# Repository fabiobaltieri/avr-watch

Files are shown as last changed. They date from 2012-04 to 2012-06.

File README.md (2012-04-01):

AVR Watch
=========

This project is small wrist watch using an AVR microcontroller, a 7-segment
display and the V-USB soft-usb stack.

License
-------

This program is free software: you can redistribute it and/or modify
it under the terms of the GNU General Public License as published by
the Free Software Foundation, either version 2 of the License, or
(at your option) any later version.

Contents
--------

    COPYING     text version of the GPL
    README      this file
    bootloader/ source directory for bootloader
    firmware/   source directory for firmware
    hardware/   source directory for the hardware design
    scripts/    support scripts

Bootloader
----------

Building the bootloader requires an avr-gcc toolchain, in the bootloader/
directory, to build run:

    make

Flashing the firmware on the device requires avrdude and a compatible hardware
programmer. Default configuration is stored at the beginning of the Makefile.
To program with the default configuration, run:

    make load

Fuses can be programmed running:

    make fuse

Firmware
--------

Building the firmwware requires an avr-gcc toolchain, in the firmware/
directory, to build run:

    make

Flashing the firmware on the device requires avrdude and a compatible hardware
programmer. Default configuration is stored at the beginning of the Makefile.
To program with the default configuration, run:

    make load

or using the bootloader (this will reset the device if possible):

    make boot

Hardware
--------

All hardware files (schematic, layout and libraries) are in CadSoft Eagle
format.

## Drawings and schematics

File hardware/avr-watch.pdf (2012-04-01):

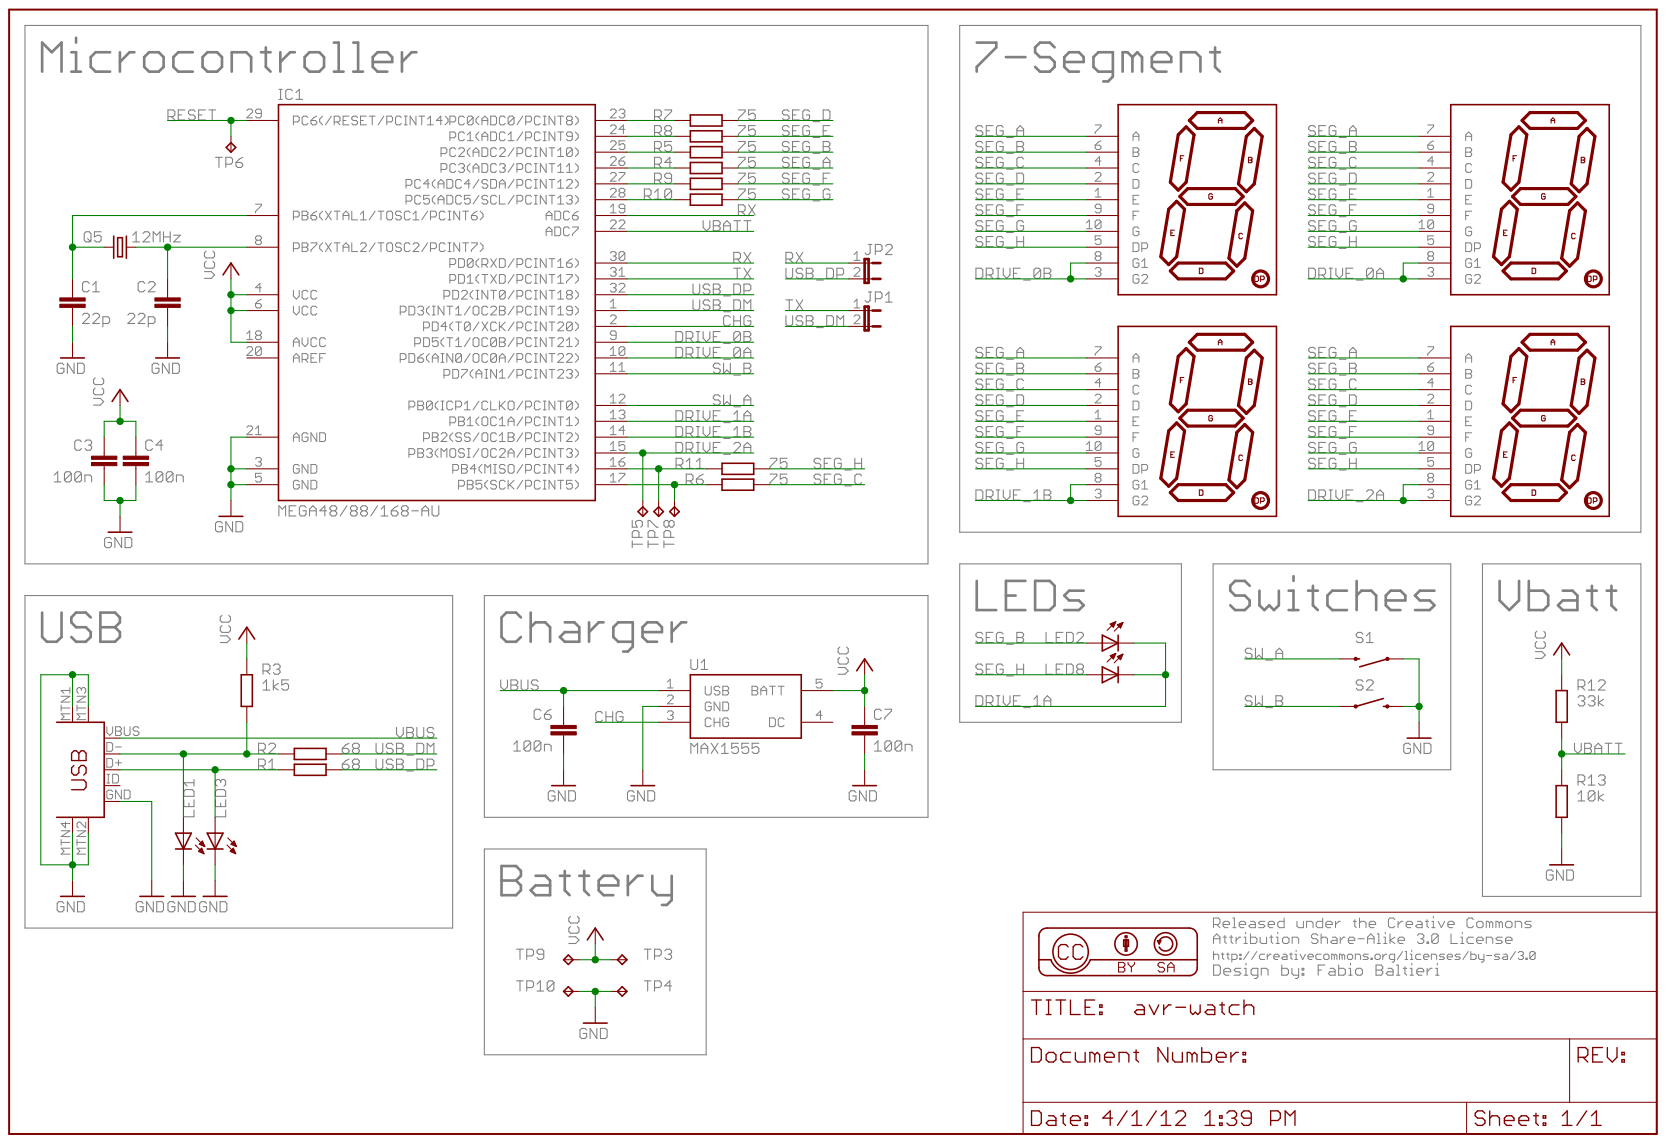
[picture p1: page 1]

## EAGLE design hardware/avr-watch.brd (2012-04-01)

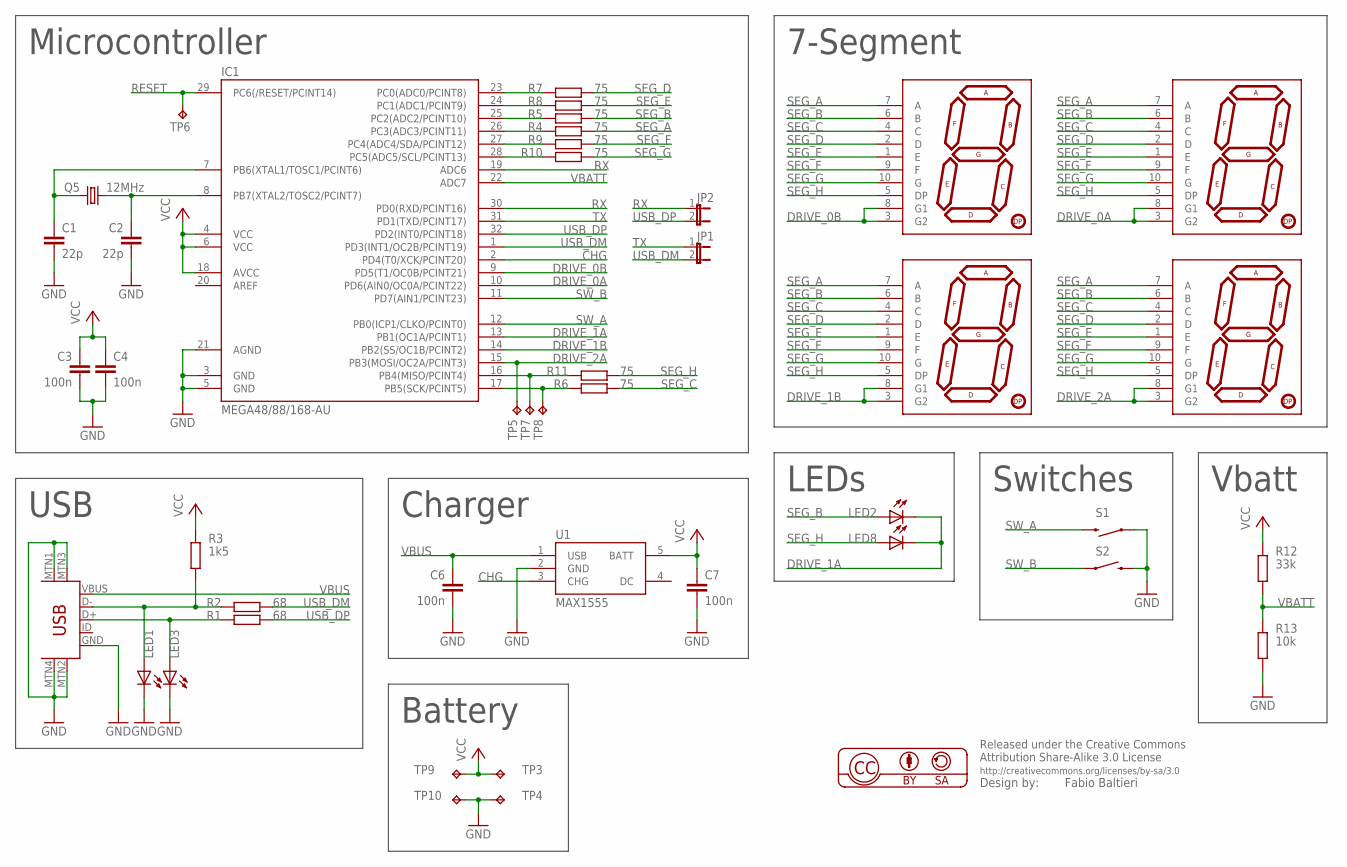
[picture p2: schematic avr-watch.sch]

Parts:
C1, C2: 22p; C0805
C3, C4, C6, C7: 100n; C0805
IC1: MEGA48/88/168-AU; TQFP32-08
JP1, JP2: JUMPER-2SMD-NC; SJ_2S
LED1, LED2, LED3, LED8: LEDCHIPLED_1206; CHIPLED_1206
Q5: 12MHz; CTS406
R1, R2: 68; R0603
R3: 1k5; R0603
R4, R5, R6, R7, R8, R9, R10, R11: 75; R0603
R12: 33k; R0603
R13: 10k; R0603
S1, S2: SWITCH-MOMENTARY-2SMD; TACTILE_SWITCH_SMD
TP3, TP4: TPB1,27; B1,27
TP5, TP6, TP7, TP8, TP9, TP10: TPTP08R; TP08R
U1: MAX1555; SOT23-5
U$1, U$3, U$4, U$5: 7-SEGMENT-DISPLAY-1"-RED; 7-SEGMENT-SMD
U$2: USB-MINIB-5PIN; USB-MINIB

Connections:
CHG: IC1.2 (PD4(T0/XCK/PCINT20)), U1.3 (CHG)
DRIVE_0A: IC1.10 (PD6(AIN0/OC0A/PCINT22)), U$3.3 (G2), U$3.8 (G1)
DRIVE_0B: IC1.9 (PD5(T1/OC0B/PCINT21)), U$1.3 (G2), U$1.8 (G1)
DRIVE_1A: IC1.13 (PB1(OC1A/PCINT1)), LED2.C, LED8.C
DRIVE_1B: IC1.14 (PB2(SS/OC1B/PCINT2)), U$4.3 (G2), U$4.8 (G1)
DRIVE_2A: IC1.15 (PB3(MOSI/OC2A/PCINT3)), TP5.TP, U$5.3 (G2), U$5.8 (G1)
GND: C1.2, C2.2, C3.2, C4.2, C6.2, C7.2, IC1.3 (GND), IC1.5 (GND), IC1.21 (AGND), LED1.C, LED3.C, R13.1, S1.1, S2.3 (2), TP4.TP, TP10.TP, U1.2 (GND), U$2.GND, U$2.MTN1 (MTN2), U$2.MTN2 (MTN3), U$2.MTN3 (MTN1), U$2.MTN4
unnamed: C2.1, IC1.8 (PB7(XTAL2/TOSC2/PCINT7)), Q5.3 (2)
unnamed: C1.1, IC1.7 (PB6(XTAL1/TOSC1/PCINT6)), Q5.1
unnamed: IC1.16 (PB4(MISO/PCINT4)), R11.1, TP7.TP
unnamed: IC1.17 (PB5(SCK/PCINT5)), R6.1, TP8.TP
unnamed: IC1.24 (PC1(ADC1/PCINT9)), R8.1
unnamed: IC1.25 (PC2(ADC2/PCINT10)), R5.1
unnamed: IC1.26 (PC3(ADC3/PCINT11)), R4.1
unnamed: IC1.27 (PC4(ADC4/SDA/PCINT12)), R9.1
unnamed: IC1.23 (PC0(ADC0/PCINT8)), R7.1
unnamed: IC1.28 (PC5(ADC5/SCL/PCINT13)), R10.1
unnamed: LED1.A, R2.1, R3.1, U$2.D-
unnamed: LED3.A, R1.1, U$2.D+
RESET: IC1.29 (PC6(/RESET/PCINT14)), TP6.TP
RX: IC1.19 (ADC6), IC1.30 (PD0(RXD/PCINT16)), JP2.1
SEG_A: R4.2, U$1.7 (A), U$3.7 (A), U$4.7 (A), U$5.7 (A)
SEG_B: LED2.A, R5.2, U$1.6 (B), U$3.6 (B), U$4.6 (B), U$5.6 (B)
SEG_C: R6.2, U$1.4 (C), U$3.4 (C), U$4.4 (C), U$5.4 (C)
SEG_D: R7.2, U$1.2 (D), U$3.2 (D), U$4.2 (D), U$5.2 (D)
SEG_E: R8.2, U$1.1 (E), U$3.1 (E), U$4.1 (E), U$5.1 (E)
SEG_F: R9.2, U$1.9 (F), U$3.9 (F), U$4.9 (F), U$5.9 (F)
SEG_G: R10.2, U$1.10 (G), U$3.10 (G), U$4.10 (G), U$5.10 (G)
SEG_H: LED8.A, R11.2, U$1.5 (DP), U$3.5 (DP), U$4.5 (DP), U$5.5 (DP)
SW_A: IC1.12 (PB0(ICP1/CLKO/PCINT0)), S1.3 (2)
SW_B: IC1.11 (PD7(AIN1/PCINT23)), S2.1
TX: IC1.31 (PD1(TXD/PCINT17)), JP1.1
USB_DM: IC1.1 (PD3(INT1/OC2B/PCINT19)), JP1.2, R2.2
USB_DP: IC1.32 (PD2(INT0/PCINT18)), JP2.2, R1.2
VBATT: IC1.22 (ADC7), R12.1, R13.2
VBUS: C6.1, U1.1 (USB), U$2.VBUS
VCC: C3.1, C4.1, C7.1, IC1.4 (VCC), IC1.6 (VCC), IC1.18 (AVCC), R3.2, R12.2, TP3.TP, TP9.TP, U1.5 (BATT)

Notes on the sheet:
USB
Microcontroller
7-Segment
LEDs
Charger
Switches
Vbatt
Battery

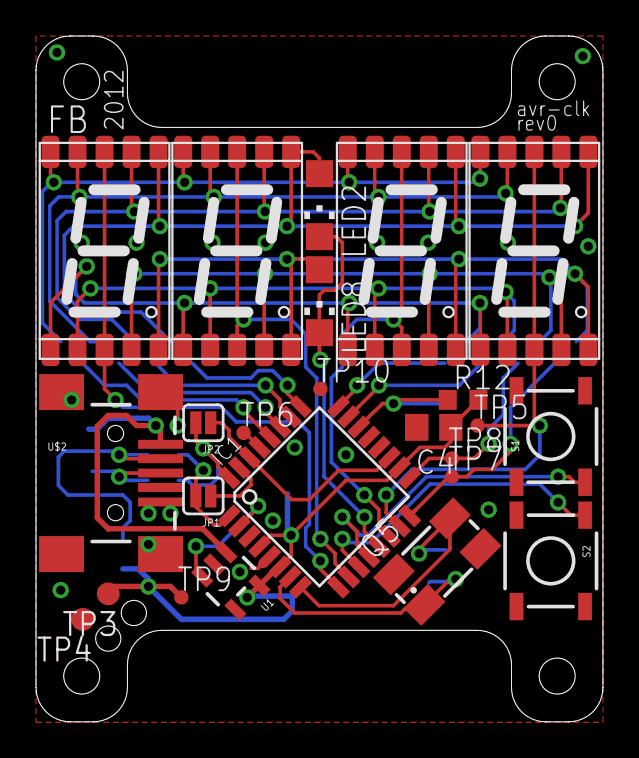
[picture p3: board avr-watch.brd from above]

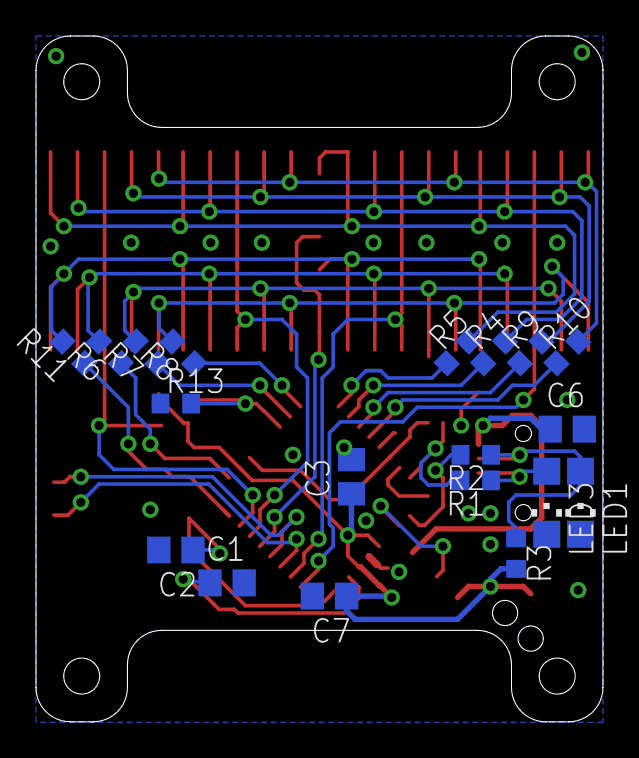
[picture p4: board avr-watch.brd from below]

Board: 2 copper layers, 31.5 x 38.1 mm, 43 parts (19 on the bottom side), 37 nets.

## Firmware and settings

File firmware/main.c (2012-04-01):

/*
 * Copyright 2012 Fabio Baltieri (fabio.baltieri@gmail.com)
 *
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
 */

#include "board.h"

#include <avr/io.h>
#include <avr/wdt.h>
#include <avr/interrupt.h>
#include <avr/sleep.h>
#include <util/delay.h>

#include "usbdrv.h"
#include "requests.h"

#include "clock.h"

/*
 * USB
 */

static void reset_cpu(void)
{
	wdt_disable();

	wdt_enable(WDTO_15MS);

	for (;;);
}

usbMsgLen_t usbFunctionSetup(uint8_t data[8])
{
	struct usbRequest *rq = (void *)data;
	static union {
		uint32_t l;
		uint8_t  b[4];
	} temp;

	switch (rq->bRequest) {
	case CUSTOM_RQ_GET_TIME:
		temp.l = time;
		usbMsgPtr = (uint8_t *)&temp;
		return sizeof(temp);
	case CUSTOM_RQ_SET_TIME:
		temp.b[0] = rq->wValue.bytes[0];
		temp.b[1] = rq->wValue.bytes[1];
		temp.b[2] = rq->wIndex.bytes[0];
		temp.b[3] = rq->wIndex.bytes[1];
		time = temp.l;
		return 0;
	case CUSTOM_RQ_RESET:
		reset_cpu();
		break;
	}

	return 0;
}

/*
 * Main & Friends
 */

static void hello(void)
{
	uint8_t i;
	drive_0(1);
	for (i = 0; i < 8; i++) {
		led_set(0xff);
		_delay_ms(33);
		led_set(0x00);
		_delay_ms(33);
	}
	drive_0(0);
}

int __attribute__((noreturn)) main(void)
{
	uint8_t i;

	/* disable watchdog */
	i = MCUSR;
	MCUSR = 0;
	wdt_disable();

	/* power down unused peripherals */
	PRR = ( (1 << PRTWI) |    /* TWI */
		(0 << PRTIM0) |   /* Timer 0 */
		(0 << PRTIM1) |   /* Timer 1 */
		(1 << PRTIM2) |   /* Timer 2 */
		(1 << PRSPI) |    /* SPI */
		(1 << PRUSART0) | /* USART0 */
		(0 << PRADC) );   /* ADC */

	/* clock */
	led_init();
	clock_init();
	hello();

	/* USB */
	usbInit();
	usbDeviceDisconnect();

	i = 0;
	while (--i) {
		_delay_ms(1);
	}

	usbDeviceConnect();

	sei();
	for (;;) {
		usbPoll();

		clock_poll();

		set_sleep_mode(SLEEP_MODE_IDLE);
		sleep_mode();
	}
}

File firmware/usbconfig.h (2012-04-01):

/*
 * Author: Fabio Baltieri
 * Original Author: Christian Starkjohann
 * Copyright: (c) 2005 by OBJECTIVE DEVELOPMENT Software GmbH
 * License: GNU GPL v2 (see License.txt)
 *
 */

#ifndef __usbconfig_h_included__
#define __usbconfig_h_included__

/*
General Description:
This file is an example configuration (with inline documentation) for the USB
driver. It configures V-USB for USB D+ connected to Port D bit 2 (which is
also hardware interrupt 0 on many devices) and USB D- to Port D bit 4. You may
wire the lines to any other port, as long as D+ is also wired to INT0 (or any
other hardware interrupt, as long as it is the highest level interrupt, see
section at the end of this file).
+ To create your own usbconfig.h file, copy this file to your project's
+ firmware source directory) and rename it to "usbconfig.h".
+ Then edit it accordingly.
*/

/* ---------------------------- Hardware Config ---------------------------- */

#define USB_CFG_IOPORTNAME      D
/* This is the port where the USB bus is connected. When you configure it to
 * "B", the registers PORTB, PINB and DDRB will be used.
 */
#define USB_CFG_DMINUS_BIT      3
/* This is the bit number in USB_CFG_IOPORT where the USB D- line is connected.
 * This may be any bit in the port.
 */
#define USB_CFG_DPLUS_BIT       2
/* This is the bit number in USB_CFG_IOPORT where the USB D+ line is connected.
 * This may be any bit in the port. Please note that D+ must also be connected
 * to interrupt pin INT0! [You can also use other interrupts, see section
 * "Optional MCU Description" below, or you can connect D- to the interrupt, as
 * it is required if you use the USB_COUNT_SOF feature. If you use D- for the
 * interrupt, the USB interrupt will also be triggered at Start-Of-Frame
 * markers every millisecond.]
 */
#define USB_CFG_CLOCK_KHZ       (F_CPU/1000)
/* Clock rate of the AVR in kHz. Legal values are 12000, 12800, 15000, 16000,
 * 16500, 18000 and 20000. The 12.8 MHz and 16.5 MHz versions of the code
 * require no crystal, they tolerate +/- 1% deviation from the nominal
 * frequency. All other rates require a precision of 2000 ppm and thus a
 * crystal!
 * Since F_CPU should be defined to your actual clock rate anyway, you should
 * not need to modify this setting.
 */
#define USB_CFG_CHECK_CRC       0
/* Define this to 1 if you want that the driver checks integrity of incoming
 * data packets (CRC checks). CRC checks cost quite a bit of code size and are
 * currently only available for 18 MHz crystal clock. You must choose
 * USB_CFG_CLOCK_KHZ = 18000 if you enable this option.
 */

/* ----------------------- Optional Hardware Config ------------------------ */

/* #define USB_CFG_PULLUP_IOPORTNAME   D */
/* If you connect the 1.5k pullup resistor from D- to a port pin instead of
 * V+, you can connect and disconnect the device from firmware by calling
 * the macros usbDeviceConnect() and usbDeviceDisconnect() (see usbdrv.h).
 * This constant defines the port on which the pullup resistor is connected.
 */
/* #define USB_CFG_PULLUP_BIT          4 */
/* This constant defines the bit number in USB_CFG_PULLUP_IOPORT (defined
 * above) where the 1.5k pullup resistor is connected. See description
 * above for details.
 */

/* --------------------------- Functional Range ---------------------------- */
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

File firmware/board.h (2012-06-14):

/* LEDs */

#define SSEG_A	PC3
#define SSEG_B	PC2
#define SSEG_D	PC0
#define SSEG_E	PC1
#define SSEG_F	PC4
#define SSEG_G	PC5
#define SSEG_C	PB5
#define SSEG_H	PB4

#define SSEG_PORT_D01	PORTD
#define SSEG_DDR_D01	DDRD
#define SSEG_PORT_D234	PORTB
#define SSEG_DDR_D234	DDRB

#define SSEG_D0	PD5 /* OC0B */
#define SSEG_D1	PD6 /* OC0A */
#define SSEG_D2	PB2 /* OC1B */
#define SSEG_D3	PB3 /* OC2A */
#define SSEG_D4	PB1 /* OC1A */

#define drive_0(x) do {					\
		if (x)					\
			SSEG_DDR_D01 |= _BV(SSEG_D0);	\
		else					\
			SSEG_DDR_D01 &= ~_BV(SSEG_D0);	\
	} while (0)
#define drive_1(x) do {					\
		if (x)					\
			SSEG_DDR_D01 |= _BV(SSEG_D1);	\
		else					\
			SSEG_DDR_D01 &= ~_BV(SSEG_D1);	\
	} while (0)
#define drive_2(x) do {					\
		if (x)					\
			SSEG_DDR_D234  |= _BV(SSEG_D2);	\
		else					\
			SSEG_DDR_D234 &= ~_BV(SSEG_D2);	\
	} while (0)
#define drive_3(x) do {					\
		if (x)					\
			SSEG_DDR_D234  |= _BV(SSEG_D3);	\
		else					\
			SSEG_DDR_D234 &= ~_BV(SSEG_D3);	\
	} while (0)
#define drive_4(x) do {					\
		if (x)					\
			SSEG_DDR_D234  |= _BV(SSEG_D4);	\
		else					\
			SSEG_DDR_D234 &= ~_BV(SSEG_D4);	\
	} while (0)

#define led_init() do {				\
		DDRC |= 0x3f;			\
		DDRB |= 0x30;			\
	} while (0)

#define led_set(x) do {						\
		PORTC = (PORTC & ~0x3f) | (x & 0x3f);		\
		PORTB = (PORTB & ~0x30) | ((x & 0xc0) >> 2);	\
	} while (0)

/* Buttons */

#define SW_A_PCINT	PCINT0
#define SW_A_PCMSK	PCMSK0
#define SW_A_PORT	PORTB
#define SW_A_PIN	PINB
#define SW_A		PB0

#define SW_B_PCINT	PCINT23
#define SW_B_PCMSK	PCMSK2
#define SW_B_PORT	PORTD
#define SW_B_PIN	PIND
#define SW_B		PD7

#define sw_init() do {				\
		SW_A_PORT |= _BV(SW_A);		\
		SW_B_PORT |= _BV(SW_B);		\
		SW_A_PCMSK |= _BV(SW_A_PCINT);	\
		SW_B_PCMSK |= _BV(SW_B_PCINT);	\
	} while (0)

#define sw_a_read() (!(SW_A_PIN & _BV(SW_A)))
#define sw_b_read() (!(SW_B_PIN & _BV(SW_B)))

/* CHG */
#define CHG_PCINT	PCINT20
#define CHG_PCMSK	PCMSK2
#define CHG_PORT	PORTD
#define CHG_PIN		PIND
#define CHG		PD4

#define chg_init() do {				\
		CHG_PORT |= _BV(CHG);		\
		CHG_PCMSK |= _BV(CHG_PCINT);	\
	} while (0)

#define chg_read() (!(CHG_PIN & _BV(CHG)))

/* Analog */

#define AIN_BATTERY	(_BV(REFS0) | 0x0e) /* measure Vbg, AVcc reference */

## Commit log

2011-12-11 hardware: initial hardware files import
    [avr-clock.brd, avr-clock.sch]
2011-12-11 hardware: add silkscreen
    [avr-clock.brd]
2011-12-12 hardware: add rx-adc connection
    [avr-clock.brd, avr-clock.sch]
2012-02-17 bootloader: Makefile: set fuse for ATmega168
2012-02-17 bootloader: setup for ATmega168 on usbasp board
2012-02-17 main: add reset_cpu request
    [main.c]
2012-03-26 hardware: change led and Vbatt resistors
    [avr-clock.brd, avr-clock.sch]
2012-03-26 firmware: add battery voltage reading function
2012-03-26 firmware: use correct usb data pins
    [usbconfig.h]
2012-03-26 firmware: fix clock display
    [clock.c]
2012-03-26 firmware: blink leds each second
2012-03-26 firmware: move real time to timer 1 (16 bits)
2012-03-26 firmware: add missing "static" declarations
    [clock.c]
2012-03-26 firmware: rework refresh standby logic
    [clock.c]
2012-03-26 firmware: add charging indication
2012-03-28 firmware: disable usb with interrupt mask to save power
2012-04-01 hardware: rename (clock -> watch)
    [avr-watch.brd, avr-watch.sch]
2012-04-01 bootloader: update copyright notice
    Keep GPL2 license, change current author, retain original author
    information.
2012-04-01 hardware: cosmetic changes, add pdf
    [avr-watch.brd, avr-watch.sch]
2012-05-09 fw: change voltage scaling formula to improve accuracy
2012-06-14 fw: change battery measurement method

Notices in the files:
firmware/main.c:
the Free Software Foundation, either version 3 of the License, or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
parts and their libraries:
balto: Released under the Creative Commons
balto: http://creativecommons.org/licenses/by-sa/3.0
